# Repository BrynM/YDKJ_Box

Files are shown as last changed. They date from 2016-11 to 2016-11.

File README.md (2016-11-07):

# You Don't Know Jack in the Box (YDKJ_Box)

## YDKJ? WTF? BBQ?

A case/box/contraption for three game show style player button controllers to be used playing [You Don't Know Jack](https://en.wikipedia.org/wiki/You_Don%27t_Know_Jack_\(video_game_series\)) (available on [Steam](http://store.steampowered.com/sub/33692/)). This package is geared toward fun and portability. The "controllers" attach to a box containing a portable PC such as a [Zotac PI320](https://www.zotac.com/us/product/mini_pcs/pi320) with a [small bluetooth keyboard](http://www.centralcomputers.com/p-383937-comkia-mobikeys-b405-bluetooth-keyboardwith-touchpadproduct.aspx) and some circuitry based on the [Arduino Micro](https://www.arduino.cc/en/Main/ArduinoBoardMicro) used as a HID keyboard. The bluetooth keyboard is required for the bonus round questions and team names despite these additional controls.

If you want to go really crazy, consider including a [portable projector](https://rif6.com/product/cube/) in the box.

## Schematic

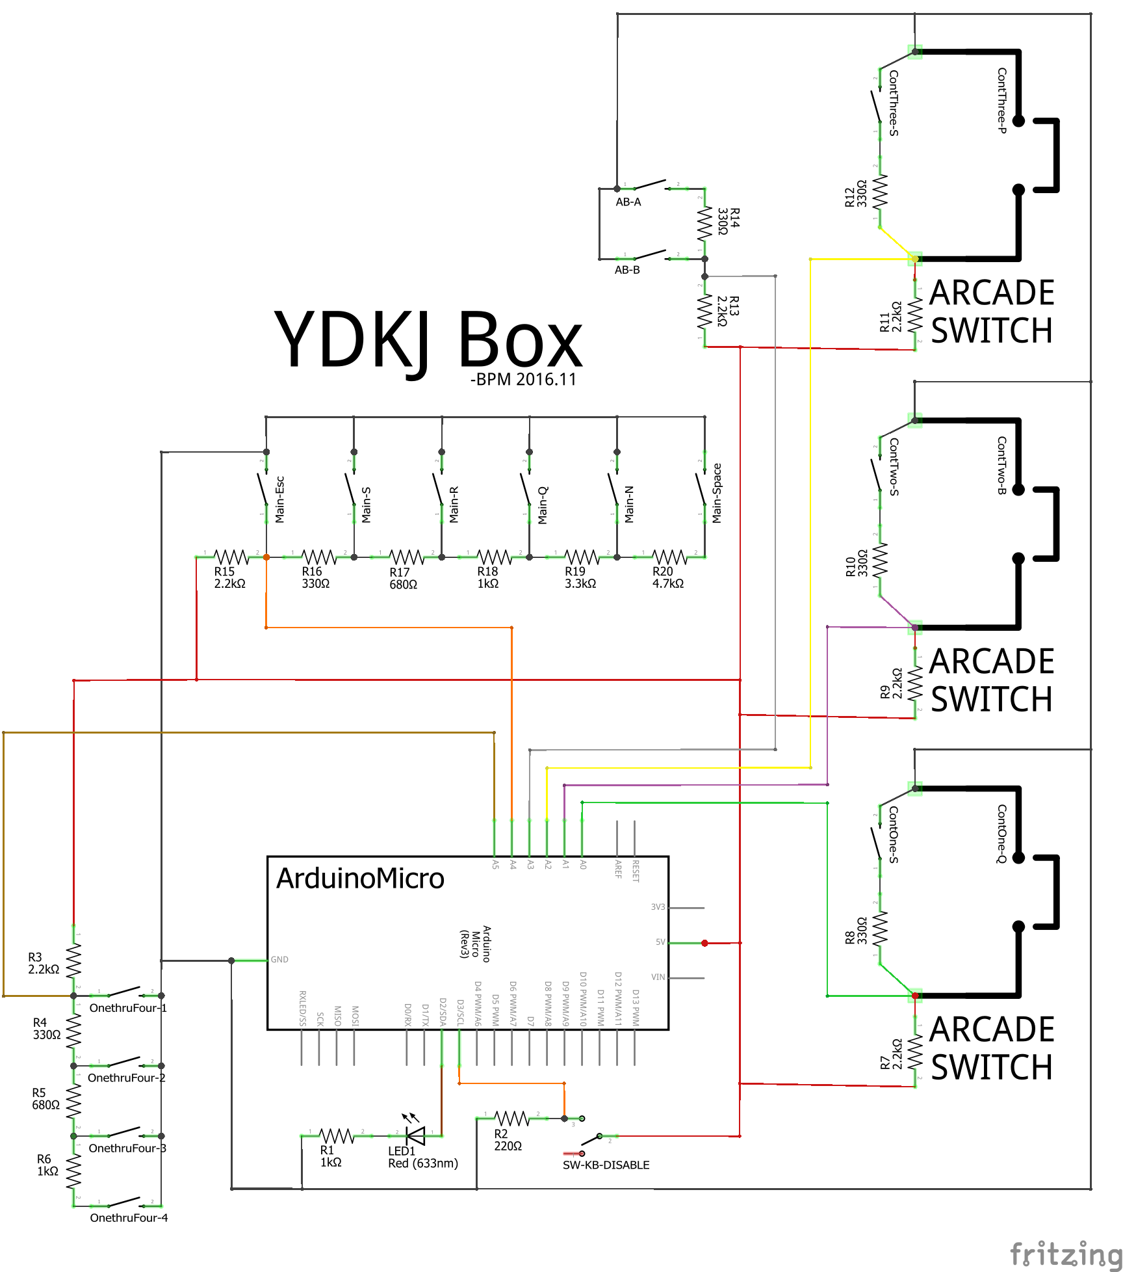
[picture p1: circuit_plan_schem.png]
Schematic


Rather than try to squeeze some weird button matrix scheme for 18 buttons into 10 digital inputs, I used linear [resistor ladders](https://en.wikipedia.org/wiki/Resistor_ladder) and grouped buttons together on the Micro's analog inputs. Each group only takes up a single analog input. In a resistor ladder, the first (primary) button on the chain will win out.

Each controller is a two step ladder with the "buzzer" arcade button in the primary position. This gives each player an equal timing chance to buzz in for an answer. Since we're basically using the Micro as a proxy for keyproesses, we can fire on input changes right away. The player can only "screw" another player after buzzing in. With the buzzer being the primary, a panicky player can squeeze both buttons at once and register their buzzer.

The rest of the buttons are meant to be mounted on the main box. They are in three groups - "OnetThruFour" for making answer selections, "AB" for making game mode selections, and "Main" for invoking the game menu and making choices with it. Each group has its own resistor ladder. The only consideration given to button order among these groups was for the Main group. With that group, the `[escape]` key is the most important and thus takes the primary spot. It should be noted that the buttons in the Main group are to be mounted onto the box exterior in the reverse order of their circuit due to this consideration.

The switch and LED are for programming the Micro. It's a little bit of a pain to have it sending keystrokes to your IDE or serial monitor while testing, so the switch disables sending keystrokes. When blocking keystrokes is enabled, the LED is lit as a warning.

## Breadboard Plan

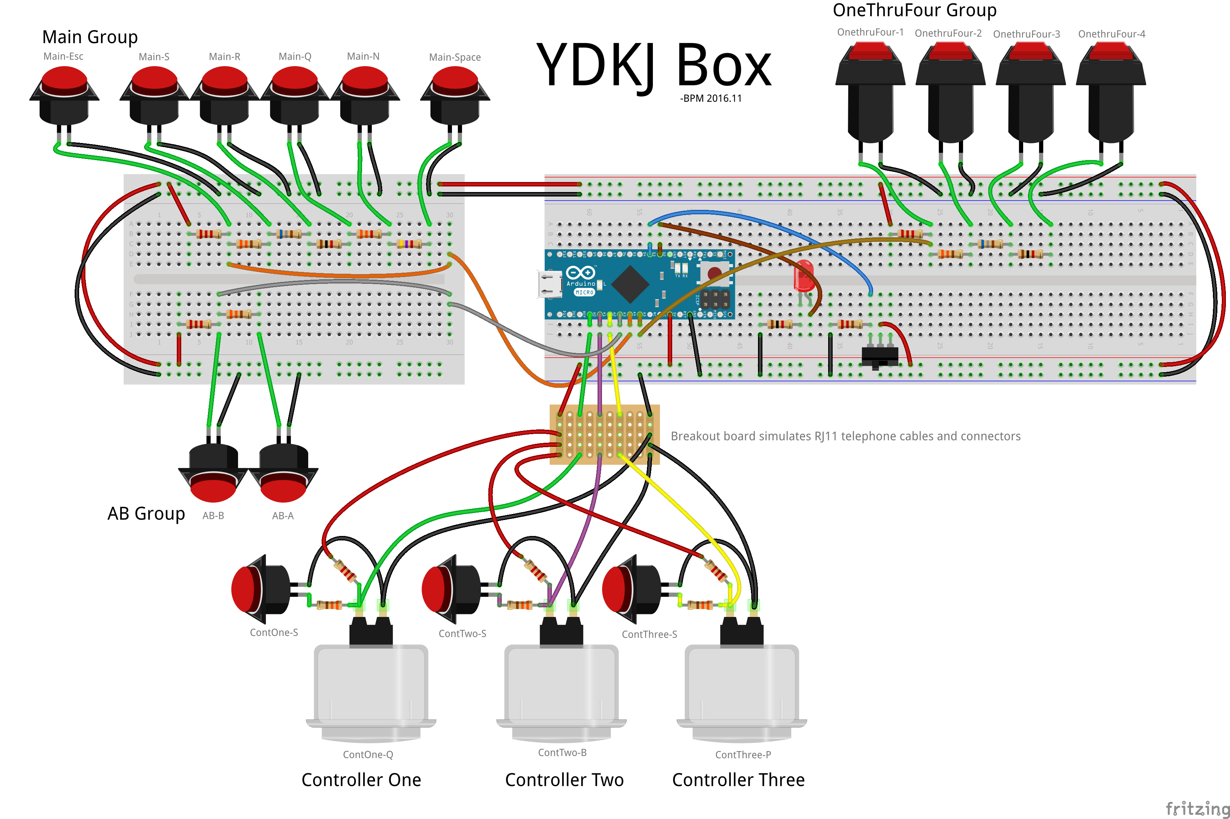
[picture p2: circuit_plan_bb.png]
Breadboard Plan


### Controller

Each controller has two buttons - the main  player "buzzer" button (in this case using arcade buttons) and a secondary "screw" button.

#### Controller Buttons

|Controller|Key(s)|Analog Value|Use|
|----|----|----|----|
|*ContOne*|`Q`|-|Player One Main Buzzer|
|*ContOne*|`S`|-|"Screw" Button|
|*ContTwo*|`B`|-|Player Two Main Buzzer|
|*ContTwo*|`S`|-|"Screw" Button|
|*ContThree*|`P`|-|Player Three Main Buzzer|
|*ContThree*|`S`|-|"Screw" Button|

### Box

Externally, the box itself has RJ11 connectors for the controllers, HDMI and power extensions for the mini PC, and the additional gameplay buttons mounted directly to it.

#### Box Buttons

|Button Group|Key(s)|Analog Value|Use|
|----|----|----|----|
|*OnetThruFour*|-|~1024|(idle input)|
|*OnetThruFour*|`1`|~0|Primary Answer, "Screw" Recipient|
|*OnetThruFour*|`2`|~130|Primary Answer, "Screw" Recipient|
|*OnetThruFour*|`3`|~315|Primary Answer, "Screw" Recipient|
|*OnetThruFour*|`4`|~480|Primary Answer|
|*AB*|`A`|-|Game Mode Selector|
|*AB*|`B`|-|Game Mode Selector|
|*Main*|`[space]`|-|Used for "skip" and misc. input|
|*Main*|`N`|-|Used for menu choices|
|*Main*|`Q`|-|Used for menu choices|
|*Main*|`R`|-|Used for menu choices|
|*Main*|`S`|-|Used for menu choices|
|*Main*|`[esc]`|-|Used to pause, bring up the menu, or dismiss things|

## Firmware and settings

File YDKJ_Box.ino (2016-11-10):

#include <Keyboard.h>
#include "box_utils.h"
#include "kb_block.h"
#include "Keystroke.h"
#include "LadderButton.h"

const int oneThroughFourPin = A5;
const int playerOnePin = A2;
int oneThroughFourVal = 0;
char lastOneThruFourKey[1];

LadderButton buttonsOneThroughFour("OneThruFour", oneThroughFourPin);
// 1023 idle
Keystroke oneThroughFour_Idle(1023, '\0');
Keystroke oneThroughFour_One(5, "1");
Keystroke oneThroughFour_Two(130, "2");
Keystroke oneThroughFour_Three(300, "3");
Keystroke oneThroughFour_Four(450, "4");

LadderButton playerOne("PlayerOne", playerOnePin);
// 1023 idle
Keystroke playerOne_Idle(1023, '\0');
Keystroke playerOne_Q(1, "q");
Keystroke playerOne_S(133, "s");

void setup() {
  Serial.begin(9600);
  wait_for_serial();

delay(1000);
  board_debug_info();
  
  setup_keyboard_block();
  setup_ladder_buttons();

  //oneThroughFour_One.set_variance(25);
  buttonsOneThroughFour.setup();
  playerOne.setup();
//  buttonsOneThroughFour.send_key(KEY_RIGHT_GUI);

//  setup_one_through_four();
}

void setup_ladder_buttons() {
}

void loop() {
  loop_keyboard_block();

  buttonsOneThroughFour.read_pin_raw();
  playerOne.read_pin_raw();


  //char keystrokeOneThroughFour[1];
  //keystrokeOneThroughFour[0] = '\0';
  //read_one_through_four(keystrokeOneThroughFour);
}

void setup_one_through_four() {
  pin_activate(oneThroughFourPin, INPUT);
  lastOneThruFourKey[0] = '\0';
}

int read_one_through_four(char *intoVar) {
  int value = get_one_through_four_value();
  char key[1];
  key[0] = '\0';

  if(value_is_between(value, 1000, 1100)) {
    // no keystroke - idle resistance
    return 0;
  } else if(value_is_between(value, -1, 51)) {
    key[0] = '1';
  } else if(value_is_between(value, 99, 151)) {
    key[0] = '2';
  } else if(value_is_between(value, 299, 351)) {
    key[0] = '3';
  } else if(value_is_between(value, 449, 501)) {
    key[0] = '4';
  #ifdef DEBUGGING
    } else {
        Serial.print("oddball one through four value: ");
        Serial.println(value);
  #endif
  }

  if(lastOneThruFourKey[0] != key[0]) {
    #ifdef DEBUGGING
      FUNC_MSG(__func__);
      Serial.print("one through four pressed - key: ");
      Serial.print(key);
      Serial.print(" val: ");
      Serial.println(value);
    #endif

    intoVar = key;
    return 1;
  }

  return 0;
}

int get_one_through_four_value() {
  int oneThroughFourCurr = analogRead(oneThroughFourPin);

  if(!value_is_near(oneThroughFourCurr, oneThroughFourVal)) {
    #ifdef DEBUGGING
      FUNC_MSG(__func__);
      Serial.print("New One-Through-Four value. Was: ");
      Serial.print(oneThroughFourVal);
    #endif

    oneThroughFourVal = oneThroughFourCurr;

    #ifdef DEBUGGING
      Serial.print(" Is: ");
      Serial.println(oneThroughFourVal);
    #endif
  }

  return oneThroughFourVal;
}

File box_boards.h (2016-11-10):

#ifndef __box_boards_h__
#define __box_boards_h__
  #if defined (__AVR_AT94K__)
    #define __BOX_BOARD__ "AT94K"
  #elif defined (__AVR_AT43USB320__)
    #define __BOX_BOARD__ "AT43USB320"
  #elif defined (__AVR_AT43USB355__)
    #define __BOX_BOARD__ "AT43USB355"
  #elif defined (__AVR_AT76C711__)
    #define __BOX_BOARD__ "AT76C711"
  #elif defined (__AVR_AT86RF401__)
    #define __BOX_BOARD__ "AT86RF401"
  #elif defined (__AVR_AT90PWM1__)
    #define __BOX_BOARD__ "AT90PWM1"
  #elif defined (__AVR_AT90PWM2__)
    #define __BOX_BOARD__ "AT90PWM2"
  #elif defined (__AVR_AT90PWM2B__)
    #define __BOX_BOARD__ "AT90PWM2B"
  #elif defined (__AVR_AT90PWM3__)
    #define __BOX_BOARD__ "AT90PWM3"
  #elif defined (__AVR_AT90PWM3B__)
    #define __BOX_BOARD__ "AT90PWM3B"
  #elif defined (__AVR_AT90PWM216__)
    #define __BOX_BOARD__ "AT90PWM216"
  #elif defined (__AVR_AT90PWM316__)
    #define __BOX_BOARD__ "AT90PWM316"
  #elif defined (__AVR_AT90PWM161__)
    #define __BOX_BOARD__ "AT90PWM161"
  #elif defined (__AVR_AT90PWM81__)
    #define __BOX_BOARD__ "AT90PWM81"
  #elif defined (__AVR_ATmega8U2__)
    #define __BOX_BOARD__ "ATmega8U2"
  #elif defined (__AVR_ATmega16M1__)
    #define __BOX_BOARD__ "ATmega16M1"
  #elif defined (__AVR_ATmega16U2__)
    #define __BOX_BOARD__ "ATmega16U2"
  #elif defined (__AVR_ATmega16U4__)
    #define __BOX_BOARD__ "ATmega16U4"
  #elif defined (__AVR_ATmega32C1__)
    #define __BOX_BOARD__ "ATmega32C1"
  #elif defined (__AVR_ATmega32M1__)
    #define __BOX_BOARD__ "ATmega32M1"
  #elif defined (__AVR_ATmega32U2__)
    #define __BOX_BOARD__ "ATmega32U2"
  #elif defined (__AVR_ATmega32U4__)
    #define __BOX_BOARD__ "ATmega32U4"
  #elif defined (__AVR_ATmega32U6__)
    #define __BOX_BOARD__ "ATmega32U6"
  #elif defined (__AVR_ATmega64C1__)
    #define __BOX_BOARD__ "ATmega64C1"
  #elif defined (__AVR_ATmega64M1__)
    #define __BOX_BOARD__ "ATmega64M1"
  #elif defined (__AVR_ATmega128__)
    #define __BOX_BOARD__ "ATmega128"
  #elif defined (__AVR_ATmega128A__)
    #define __BOX_BOARD__ "ATmega128A"
  #elif defined (__AVR_ATmega1280__)
    #define __BOX_BOARD__ "ATmega1280"
  #elif defined (__AVR_ATmega1281__)
    #define __BOX_BOARD__ "ATmega1281"
  #elif defined (__AVR_ATmega1284__)
    #define __BOX_BOARD__ "ATmega1284"
  #elif defined (__AVR_ATmega1284P__)
    #define __BOX_BOARD__ "ATmega1284P"
  #elif defined (__AVR_ATmega128RFA1__)
    #define __BOX_BOARD__ "ATmega128RFA1"
  #elif defined (__AVR_ATmega1284RFR2__)
    #define __BOX_BOARD__ "ATmega1284RFR2"
  #elif defined (__AVR_ATmega128RFR2__)
    #define __BOX_BOARD__ "ATmega128RFR2"
  #elif defined (__AVR_ATmega2564RFR2__)
    #define __BOX_BOARD__ "ATmega2564RFR2"
  #elif defined (__AVR_ATmega256RFR2__)
    #define __BOX_BOARD__ "ATmega256RFR2"
  #elif defined (__AVR_ATmega2560__)
    #define __BOX_BOARD__ "ATmega2560"
  #elif defined (__AVR_ATmega2561__)
    #define __BOX_BOARD__ "ATmega2561"
  #elif defined (__AVR_AT90CAN32__)
    #define __BOX_BOARD__ "AT90CAN32"
  #elif defined (__AVR_AT90CAN64__)
    #define __BOX_BOARD__ "AT90CAN64"
  #elif defined (__AVR_AT90CAN128__)
    #define __BOX_BOARD__ "AT90CAN128"
  #elif defined (__AVR_AT90USB82__)
    #define __BOX_BOARD__ "AT90USB82"
  #elif defined (__AVR_AT90USB162__)
    #define __BOX_BOARD__ "AT90USB162"
  #elif defined (__AVR_AT90USB646__)
    #define __BOX_BOARD__ "AT90USB646"
  #elif defined (__AVR_AT90USB647__)
    #define __BOX_BOARD__ "AT90USB647"
  #elif defined (__AVR_AT90USB1286__)
    #define __BOX_BOARD__ "AT90USB1286"
  #elif defined (__AVR_AT90USB1287__)
    #define __BOX_BOARD__ "AT90USB1287"
  #elif defined (__AVR_ATmega644RFR2__)
    #define __BOX_BOARD__ "ATmega644RFR2"
  #elif defined (__AVR_ATmega64RFR2__)
    #define __BOX_BOARD__ "ATmega64RFR2"
  #elif defined (__AVR_ATmega64__)
    #define __BOX_BOARD__ "ATmega64"
  #elif defined (__AVR_ATmega64A__)
    #define __BOX_BOARD__ "ATmega64A"
  #elif defined (__AVR_ATmega640__)
    #define __BOX_BOARD__ "ATmega640"
  #elif defined (__AVR_ATmega644__)
    #define __BOX_BOARD__ "ATmega644"
  #elif defined (__AVR_ATmega644A__)
    #define __BOX_BOARD__ "ATmega644A"
  #elif defined (__AVR_ATmega644P__)
    #define __BOX_BOARD__ "ATmega644P"
  #elif defined (__AVR_ATmega644PA__)
    #define __BOX_BOARD__ "ATmega644PA"
  #elif defined (__AVR_ATmega645__)
    #define __BOX_BOARD__ "ATmega645"
  #elif defined (__AVR_ATmega645A__)
    #define __BOX_BOARD__ "ATmega645A"
  #elif defined (__AVR_ATmega645P__)
    #define __BOX_BOARD__ "ATmega645P"
  #elif defined (__AVR_ATmega6450__)
    #define __BOX_BOARD__ "ATmega6450"
  #elif defined (__AVR_ATmega6450A__)
    #define __BOX_BOARD__ "ATmega6450A"
  #elif defined (__AVR_ATmega6450P__)
    #define __BOX_BOARD__ "ATmega6450P"
  #elif defined (__AVR_ATmega649__)
    #define __BOX_BOARD__ "ATmega649"
  #elif defined (__AVR_ATmega649A__)
    #define __BOX_BOARD__ "ATmega649A"
  #elif defined (__AVR_ATmega6490__)
    #define __BOX_BOARD__ "ATmega6490"
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

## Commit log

2016-11-06 rename for arduino IDE
2016-11-07 fritzing routed
    [one_through_four.fzz]
2016-11-07 renamed fritzing file
    [circuit_plan.fzz]
2016-11-07 add name to schematic; export fritzing
    [circuit_plan.fzz]
2016-11-07 better switch/r2 schem layout
    [circuit_plan.fzz]
2016-11-07 schem layout tweaks
    [circuit_plan.fzz]
2016-11-07 cleaner schematic layout
    [circuit_plan.fzz]
2016-11-07 document buttons, suggest projector
2016-11-07 more button details in readme
2016-11-07 update fritzig
    [circuit_plan.fzz]
2016-11-07 duh - resistor ladders override too
2016-11-07 link to resistor ladders
2016-11-07 add screw recipient to appropriate buttons
2016-11-07 labels for breadboard
    [circuit_plan.fzz]
2016-11-08 fix prototype button output
    [YDKJ_Box.ino]
